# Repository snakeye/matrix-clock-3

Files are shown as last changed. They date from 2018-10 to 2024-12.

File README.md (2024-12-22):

# LED Matrix Clock v3

## Overview
Imagine combining the charm of retro LED displays with modern smart technology. **LED Matrix Clock v3** is a creative DIY project that transforms five 8x8 LED matrices into a sleek timepiece. Powered by an ESP8266 microcontroller, this clock not only displays the current time but also keeps it accurate by syncing with an NTP server. The DS3231 RTC module ensures reliability, while automatic daylight saving adjustments make it smarter than your average clock. Built using the Arduino framework and developed in the PlatformIO environment, this project is a perfect blend of classic aesthetics and cutting-edge convenience.

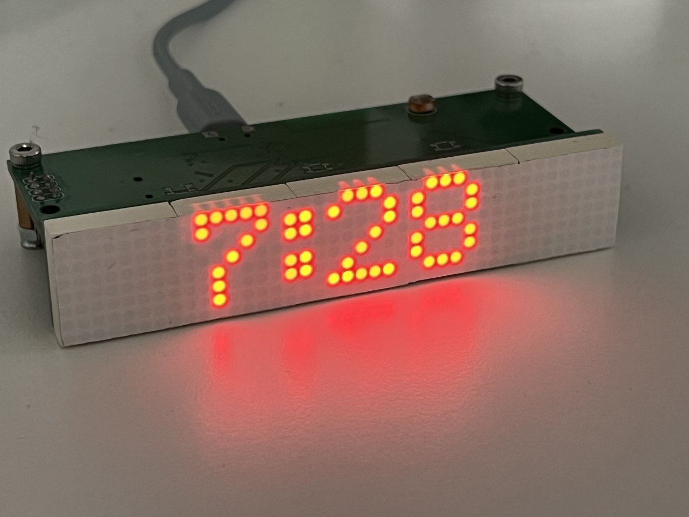
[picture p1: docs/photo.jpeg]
LED Matrix Clock v3


## Features
- **Time Display**: Shows the current time in the local time zone.
- **Automatic Daylight Calculation**: Adjusts for daylight saving time automatically.
- **NTP Synchronization**: Regular updates to the RTC clock via NTP ensure time accuracy.
- **Automatic Brightness**: The display brightness is adjusted according to ambient lighting.

## Hardware Requirements
- **ESP8266 (ESP-12 Module)**
- **5 x 8x8 LED Matrices using MAX7219 drivers**
- **DS3231 RTC Module**

## Software Requirements
- **PlatformIO** (installed via Python Pipenv)
- **Arduino Framework**
- **Python 3.x**

## Installation Instructions

### 1. Clone the Repository
```bash
git clone https://github.com/snakeye/matrix-clock-3.git
cd matrix-clock-3
```

### 3. Set Up the Environment
Ensure you have **Python 3.x** installed. Use Pipenv to install PlatformIO and set up the environment:
```bash
pip install pipenv
pipenv install --dev
pipenv shell
```
This command will install PlatformIO and any additional dependencies needed for the project.

### 2. Configure WiFi Connection
Before building the firmware, set up your WiFi connection:
1. Locate the file `src/config.cpp.example` in the repository.
2. Rename the file to `src/config.cpp`:
   ```bash
   mv src/config.cpp.example src/config.cpp
   ```
3. Open `src/config.cpp` in a text editor and update the placeholders with your WiFi network name (SSID) and password:
   ```cpp
   const char* ssid = "YourNetworkName";
   const char* password = "YourNetworkPassword";
   ```

### 4. Build the Firmware
Use the following command within the Pipenv shell to build the firmware:
```bash
platformio run
```

### 5. Upload the Firmware
Ensure your ESP8266 is connected via USB, and upload the firmware using:
```bash
platformio run --target upload
```
Following updates can be performed using OTA. Discover devices' IP address and run the following command:
```bash
platformio run --target upload --upload-port 192.168.1.179
```

## Usage
Once the firmware is uploaded, the clock will start running and display the current time. It will automatically adjust for daylight saving time and periodically synchronize with an NTP server.

## Troubleshooting
- Ensure your ESP8266 module is properly connected and powered.
- If the upload fails, check the USB connection and the selected upload port in `platformio.ini`.
- Verify your Wi-Fi credentials are correctly configured in the `src/config.cpp` file.

## License
This project is licensed under the MIT License. See the LICENSE file for more details.

## Contributions
Contributions are welcome! Please fork the repository and create a pull request with your improvements or fixes.

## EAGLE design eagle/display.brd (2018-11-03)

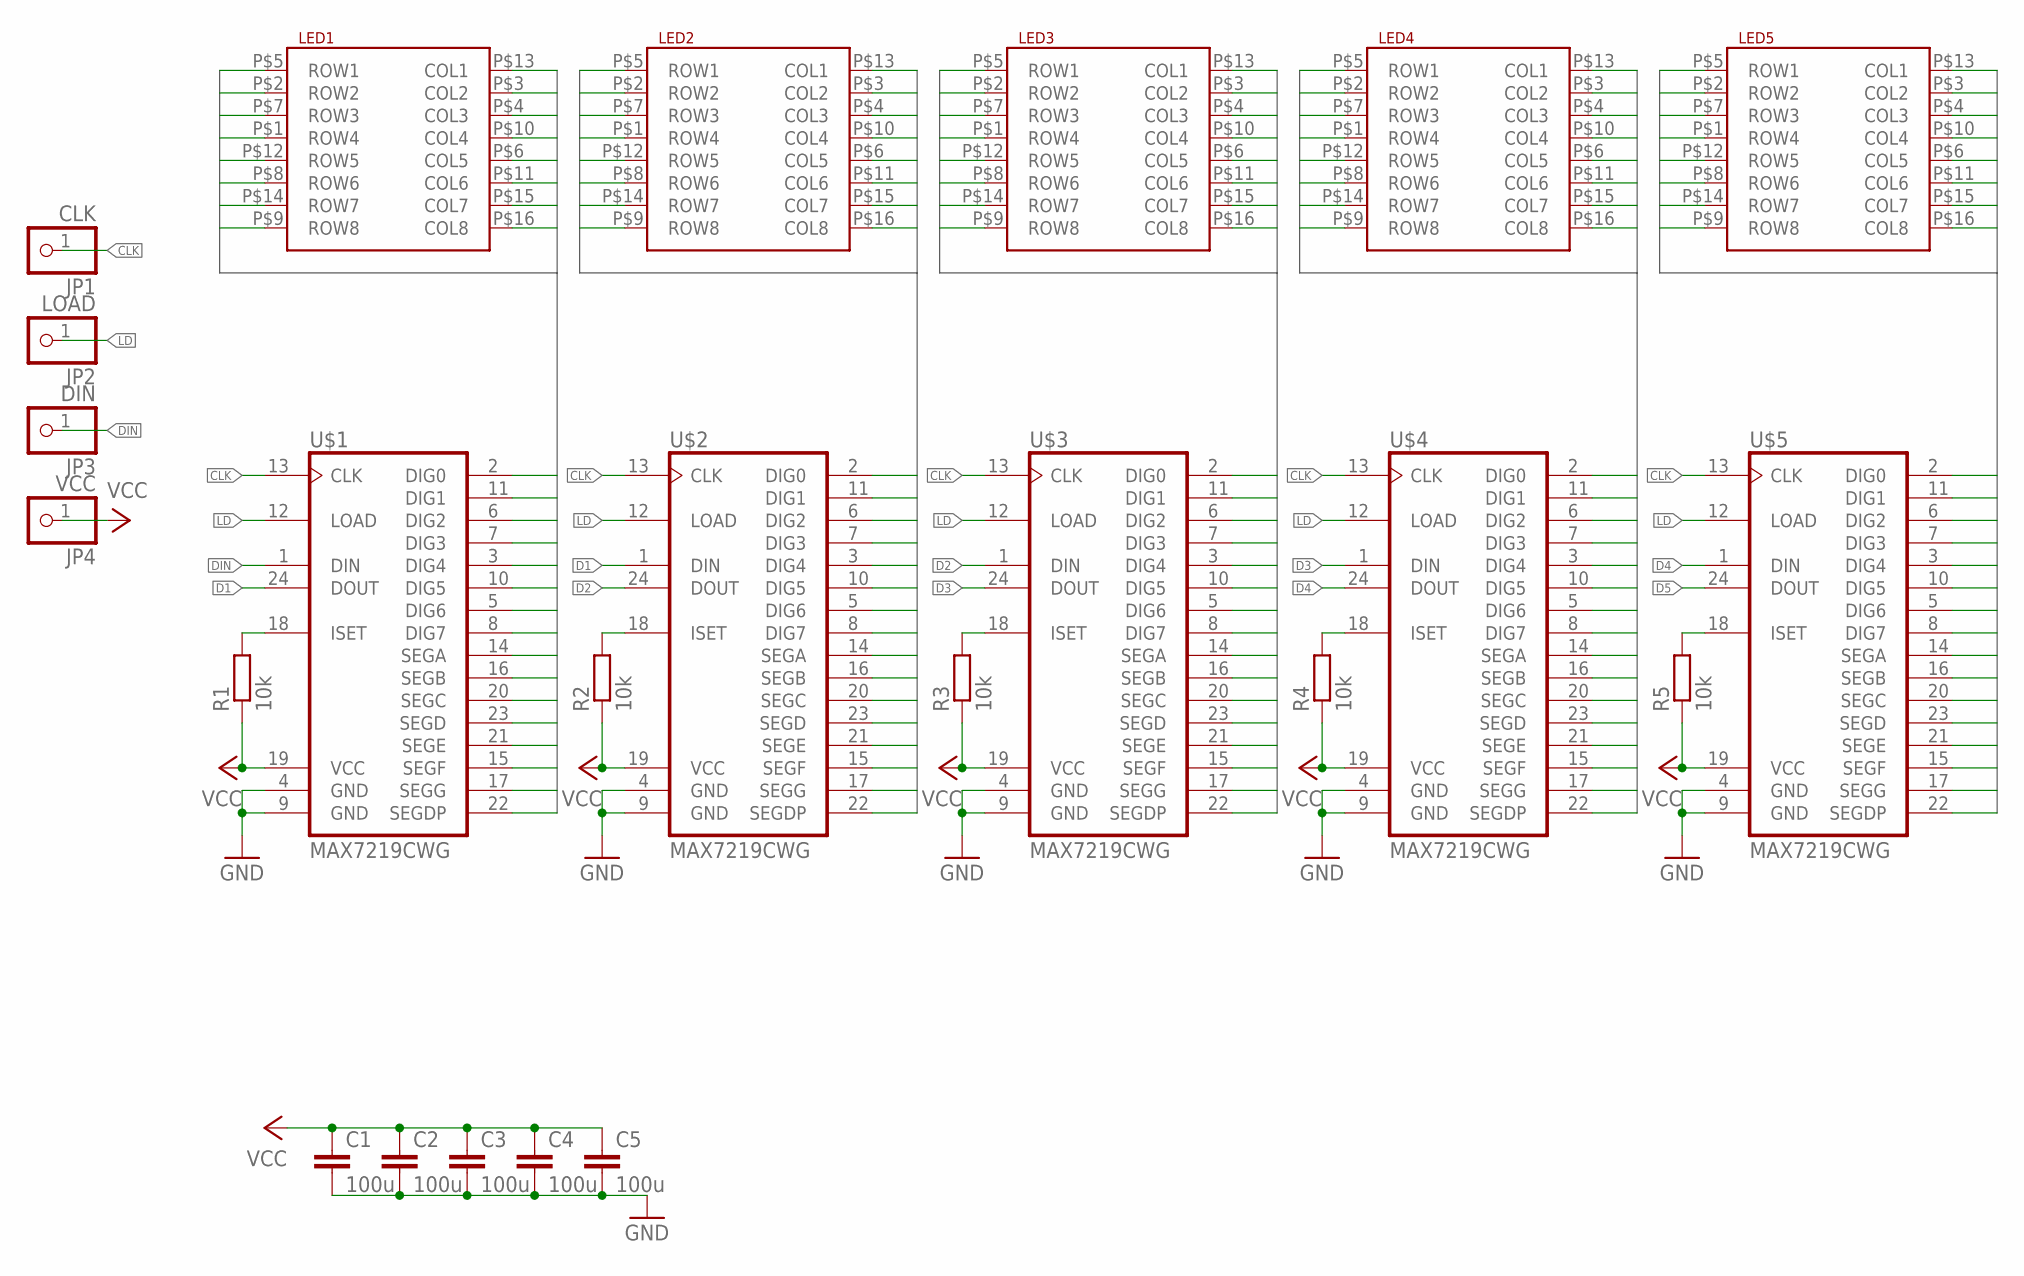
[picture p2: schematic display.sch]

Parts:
C1, C2, C3, C4, C5: 100u; C0805
JP1: CLK; 1X01
JP2: LOAD; 1X01
JP3: DIN; 1X01
JP4: VCC; 1X01
LED1, LED2, LED3, LED4, LED5: LED_8X8_MATRIX07088BH; MATRIX_8X8_20MM
R1, R2, R3, R4, R5: 10k; R0805
U$1, U$2, U$3, U$4, U$5: MAX7219CWG; SO24L

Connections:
CLK: JP1.1, U$1.13 (CLK), U$2.13 (CLK), U$3.13 (CLK), U$4.13 (CLK), U$5.13 (CLK)
D1: U$1.24 (DOUT), U$2.1 (DIN)
D2: U$2.24 (DOUT), U$3.1 (DIN)
D3: U$3.24 (DOUT), U$4.1 (DIN)
D4: U$4.24 (DOUT), U$5.1 (DIN)
D5: U$5.24 (DOUT)
DIN: JP3.1, U$1.1 (DIN)
GND: C1.2, C2.2, C3.2, C4.2, C5.2, U$1.4 (GND), U$1.9 (GND), U$2.4 (GND), U$2.9 (GND), U$3.4 (GND), U$3.9 (GND), U$4.4 (GND), U$4.9 (GND), U$5.4 (GND), U$5.9 (GND)
LD: JP2.1, U$1.12 (LOAD), U$2.12 (LOAD), U$3.12 (LOAD), U$4.12 (LOAD), U$5.12 (LOAD)
MATRIX1_ANODE1: LED1.P$5 (ROW1), U$1.14 (SEGA)
MATRIX1_ANODE2: LED1.P$2 (ROW2), U$1.16 (SEGB)
MATRIX1_ANODE3: LED1.P$7 (ROW3), U$1.20 (SEGC)
MATRIX1_ANODE4: LED1.P$1 (ROW4), U$1.23 (SEGD)
MATRIX1_ANODE5: LED1.P$12 (ROW5), U$1.21 (SEGE)
MATRIX1_ANODE6: LED1.P$8 (ROW6), U$1.15 (SEGF)
MATRIX1_ANODE7: LED1.P$14 (ROW7), U$1.17 (SEGG)
MATRIX1_ANODE8: LED1.P$9 (ROW8), U$1.22 (SEGDP)
MATRIX1_CATHODE1: LED1.P$13 (COL1), U$1.2 (DIG0)
MATRIX1_CATHODE2: LED1.P$3 (COL2), U$1.11 (DIG1)
MATRIX1_CATHODE3: LED1.P$4 (COL3), U$1.6 (DIG2)
MATRIX1_CATHODE4: LED1.P$10 (COL4), U$1.7 (DIG3)
MATRIX1_CATHODE5: LED1.P$6 (COL5), U$1.3 (DIG4)
MATRIX1_CATHODE6: LED1.P$11 (COL6), U$1.10 (DIG5)
MATRIX1_CATHODE7: LED1.P$15 (COL7), U$1.5 (DIG6)
MATRIX1_CATHODE8: LED1.P$16 (COL8), U$1.8 (DIG7)
MATRIX2_ANODE1: LED2.P$5 (ROW1), U$2.14 (SEGA)
MATRIX2_ANODE2: LED2.P$2 (ROW2), U$2.16 (SEGB)
MATRIX2_ANODE3: LED2.P$7 (ROW3), U$2.20 (SEGC)
MATRIX2_ANODE4: LED2.P$1 (ROW4), U$2.23 (SEGD)
MATRIX2_ANODE5: LED2.P$12 (ROW5), U$2.21 (SEGE)
MATRIX2_ANODE6: LED2.P$8 (ROW6), U$2.15 (SEGF)
MATRIX2_ANODE7: LED2.P$14 (ROW7), U$2.17 (SEGG)
MATRIX2_ANODE8: LED2.P$9 (ROW8), U$2.22 (SEGDP)
MATRIX2_CATHODE1: LED2.P$13 (COL1), U$2.2 (DIG0)
MATRIX2_CATHODE2: LED2.P$3 (COL2), U$2.11 (DIG1)
MATRIX2_CATHODE3: LED2.P$4 (COL3), U$2.6 (DIG2)
MATRIX2_CATHODE4: LED2.P$10 (COL4), U$2.7 (DIG3)
MATRIX2_CATHODE5: LED2.P$6 (COL5), U$2.3 (DIG4)
MATRIX2_CATHODE6: LED2.P$11 (COL6), U$2.10 (DIG5)
MATRIX2_CATHODE7: LED2.P$15 (COL7), U$2.5 (DIG6)
MATRIX2_CATHODE8: LED2.P$16 (COL8), U$2.8 (DIG7)
MATRIX3_ANODE1: LED3.P$5 (ROW1), U$3.14 (SEGA)
MATRIX3_ANODE2: LED3.P$2 (ROW2), U$3.16 (SEGB)
MATRIX3_ANODE3: LED3.P$7 (ROW3), U$3.20 (SEGC)
MATRIX3_ANODE4: LED3.P$1 (ROW4), U$3.23 (SEGD)
MATRIX3_ANODE5: LED3.P$12 (ROW5), U$3.21 (SEGE)
MATRIX3_ANODE6: LED3.P$8 (ROW6), U$3.15 (SEGF)
MATRIX3_ANODE7: LED3.P$14 (ROW7), U$3.17 (SEGG)
MATRIX3_ANODE8: LED3.P$9 (ROW8), U$3.22 (SEGDP)
MATRIX3_CATHODE1: LED3.P$13 (COL1), U$3.2 (DIG0)
MATRIX3_CATHODE2: LED3.P$3 (COL2), U$3.11 (DIG1)
MATRIX3_CATHODE3: LED3.P$4 (COL3), U$3.6 (DIG2)
MATRIX3_CATHODE4: LED3.P$10 (COL4), U$3.7 (DIG3)
MATRIX3_CATHODE5: LED3.P$6 (COL5), U$3.3 (DIG4)
MATRIX3_CATHODE6: LED3.P$11 (COL6), U$3.10 (DIG5)
MATRIX3_CATHODE7: LED3.P$15 (COL7), U$3.5 (DIG6)
MATRIX3_CATHODE8: LED3.P$16 (COL8), U$3.8 (DIG7)
MATRIX4_ANODE1: LED4.P$5 (ROW1), U$4.14 (SEGA)
MATRIX4_ANODE2: LED4.P$2 (ROW2), U$4.16 (SEGB)
MATRIX4_ANODE3: LED4.P$7 (ROW3), U$4.20 (SEGC)
MATRIX4_ANODE4: LED4.P$1 (ROW4), U$4.23 (SEGD)
MATRIX4_ANODE5: LED4.P$12 (ROW5), U$4.21 (SEGE)
MATRIX4_ANODE6: LED4.P$8 (ROW6), U$4.15 (SEGF)
MATRIX4_ANODE7: LED4.P$14 (ROW7), U$4.17 (SEGG)
MATRIX4_ANODE8: LED4.P$9 (ROW8), U$4.22 (SEGDP)
MATRIX4_CATHODE1: LED4.P$13 (COL1), U$4.2 (DIG0)
MATRIX4_CATHODE2: LED4.P$3 (COL2), U$4.11 (DIG1)
MATRIX4_CATHODE3: LED4.P$4 (COL3), U$4.6 (DIG2)
MATRIX4_CATHODE4: LED4.P$10 (COL4), U$4.7 (DIG3)
MATRIX4_CATHODE5: LED4.P$6 (COL5), U$4.3 (DIG4)
MATRIX4_CATHODE6: LED4.P$11 (COL6), U$4.10 (DIG5)
MATRIX4_CATHODE7: LED4.P$15 (COL7), U$4.5 (DIG6)
MATRIX4_CATHODE8: LED4.P$16 (COL8), U$4.8 (DIG7)
MATRIX5_ANODE1: LED5.P$5 (ROW1), U$5.14 (SEGA)
MATRIX5_ANODE2: LED5.P$2 (ROW2), U$5.16 (SEGB)
MATRIX5_ANODE3: LED5.P$7 (ROW3), U$5.20 (SEGC)
MATRIX5_ANODE4: LED5.P$1 (ROW4), U$5.23 (SEGD)
MATRIX5_ANODE5: LED5.P$12 (ROW5), U$5.21 (SEGE)
MATRIX5_ANODE6: LED5.P$8 (ROW6), U$5.15 (SEGF)
MATRIX5_ANODE7: LED5.P$14 (ROW7), U$5.17 (SEGG)
MATRIX5_ANODE8: LED5.P$9 (ROW8), U$5.22 (SEGDP)
MATRIX5_CATHODE1: LED5.P$13 (COL1), U$5.2 (DIG0)
MATRIX5_CATHODE2: LED5.P$3 (COL2), U$5.11 (DIG1)
MATRIX5_CATHODE3: LED5.P$4 (COL3), U$5.6 (DIG2)
MATRIX5_CATHODE4: LED5.P$10 (COL4), U$5.7 (DIG3)
MATRIX5_CATHODE5: LED5.P$6 (COL5), U$5.3 (DIG4)
MATRIX5_CATHODE6: LED5.P$11 (COL6), U$5.10 (DIG5)
MATRIX5_CATHODE7: LED5.P$15 (COL7), U$5.5 (DIG6)
MATRIX5_CATHODE8: LED5.P$16 (COL8), U$5.8 (DIG7)
unnamed: R5.2, U$5.18 (ISET)
unnamed: R1.2, U$1.18 (ISET)
unnamed: R2.2, U$2.18 (ISET)
unnamed: R3.2, U$3.18 (ISET)
unnamed: R4.2, U$4.18 (ISET)
VCC: C1.1, C2.1, C3.1, C4.1, C5.1, JP4.1, R1.1, R2.1, R3.1, R4.1, R5.1, U$1.19 (VCC), U$2.19 (VCC), U$3.19 (VCC), U$4.19 (VCC), U$5.19 (VCC)

Board: 2 copper layers, 24 parts (15 on the bottom side), 94 nets, no tracks yet.

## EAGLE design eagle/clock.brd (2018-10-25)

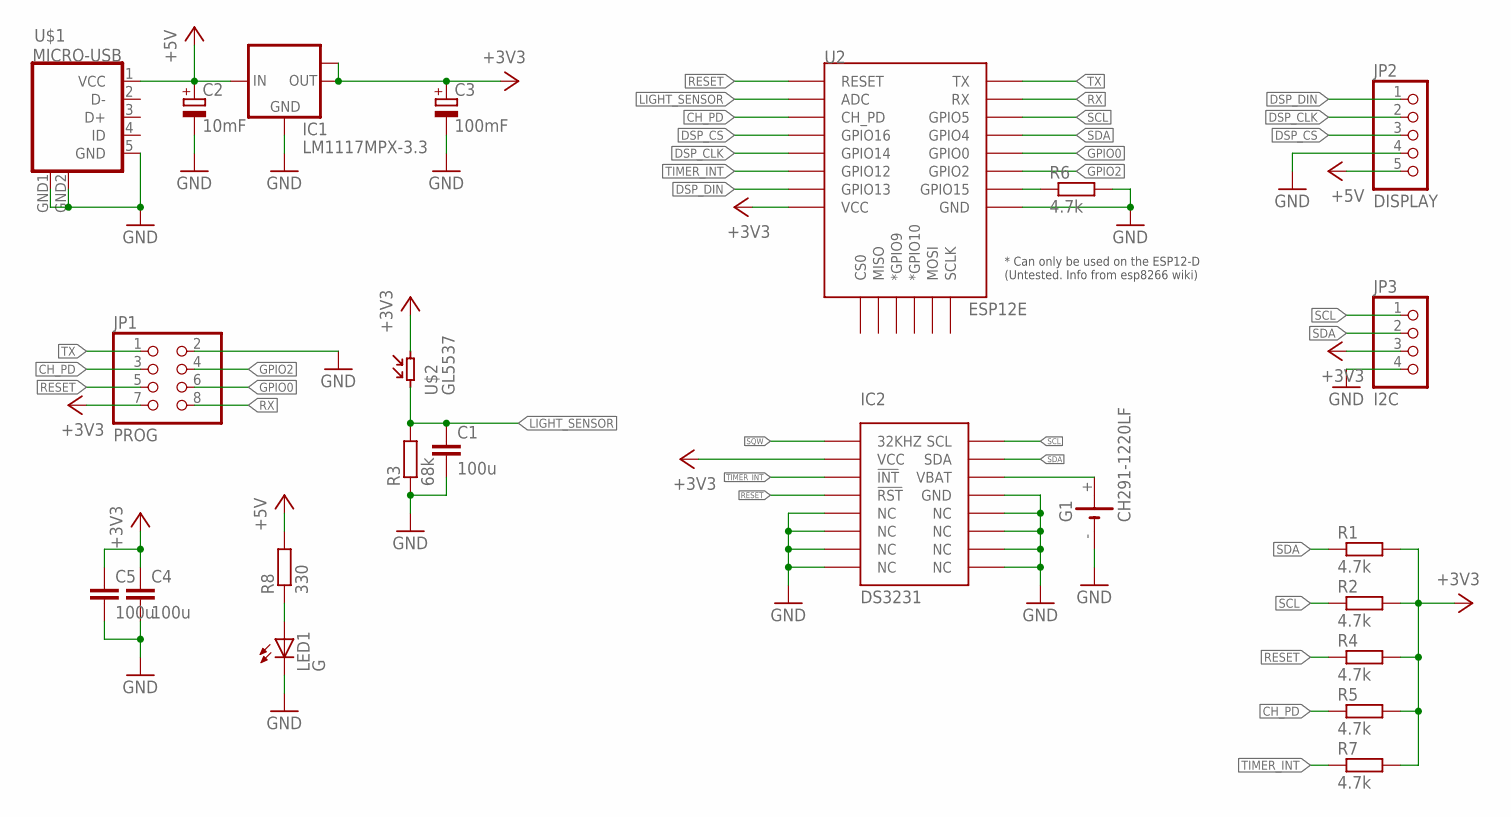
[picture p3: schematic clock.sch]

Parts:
C1, C4, C5: 100u; C0805
C2: 10mF; A/3216-18W
C3: 100mF; A/3216-18W
G1: CH291-1220LF
IC1: LM1117MPX-3.3; SOT223
IC2: DS3231; SOIC-16W
JP1: PROG; 2X04
JP2: DISPLAY; 1X05
JP3: I2C; 1X04
LED1: G; CHIPLED_0805
R1, R2, R4, R5, R6, R7: 4.7k; M0805
R3: 68k; M0805
R8: 330; M0805
U2: ESP12E; ESP12E-SMD
U$1: MICRO-USB
U$2: GL5537; GL55

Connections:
+3V3: C3.+, C4.1, C5.1, IC1.2 (OUT), IC1.TAB (OUT1), IC2.2 (VCC), JP1.7, JP3.3, R1.2, R2.2, R4.2, R5.2, R7.2, U2.VCC, U$2.P$2
+5V: C2.+, IC1.3 (IN), JP2.5, R8.2, U$1.1 (VCC)
CH_PD: JP1.3, R5.1, U2.CH_PD
DSP_CLK: JP2.2, U2.GPIO14
DSP_CS: JP2.3, U2.GPIO16
DSP_DIN: JP2.1, U2.GPIO13
GND: C1.2, C2.-, C3.-, C4.2, C5.2, G1.-, IC1.1 (GND), IC2.5 (NC), IC2.6 (NC), IC2.7 (NC), IC2.8 (NC), IC2.9 (NC), IC2.10 (NC), IC2.11 (NC), IC2.12 (NC), IC2.13 (GND), JP1.2, JP2.4, JP3.4, LED1.C, R3.1, R6.2, U2.GND, U$1.5 (GND), U$1.GND1 (GND), U$1.GND2 (GND)
GPIO0: JP1.6, U2.GPIO0
GPIO2: JP1.4, U2.GPIO2
GPIO15: R6.1, U2.GPIO15
LIGHT_SENSOR: C1.1, R3.2, U2.ADC, U$2.P$1
unnamed: LED1.A, R8.1
unnamed: G1.+, IC2.14 (VBAT)
RESET: IC2.4 (!RST), JP1.5, R4.1, U2.RESET
RX: JP1.8, U2.RXD0 (RX)
SCL: IC2.16 (SCL), JP3.1, R2.1, U2.GPIO5
SDA: IC2.15 (SDA), JP3.2, R1.1, U2.GPIO4
SQW: IC2.1 (32KHZ)
TIMER_INT: IC2.3 (!INT), R7.1, U2.GPIO12
TX: JP1.1, U2.TXD0 (TX)

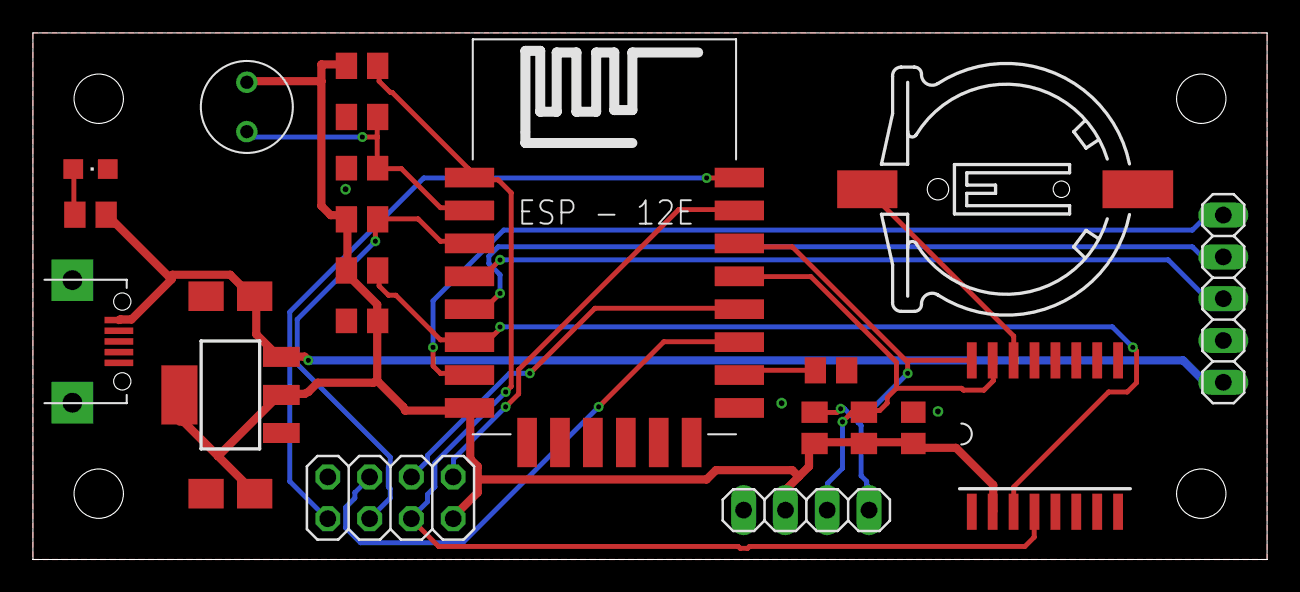
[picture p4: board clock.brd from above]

Board: 2 copper layers, 75.0 x 32.0 mm, 23 parts (0 on the bottom side), 19 nets.

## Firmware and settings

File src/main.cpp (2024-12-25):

#include <Arduino.h>

//
#include <Time.h>
#include <TimeLib.h>

#include <Timezone.h>

//
#include <WiFiUdp.h>
#include <NTPClient.h>

//
#include <Wire.h>
#include <RtcDS3231.h>

//
#include <DNSServer.h>

//
#include <ESP8266mDNS.h>
#include <ArduinoOTA.h>

//
#include <RecurringTask.h>

//
#include <OneButton.h>

#include "LedMatrixDisplay.h"

#include "config.h"

#define INTENSITY_MEASUREMENTS 40

#define PIN_BUTTON 2

#define MODE_RESET_DELAY 15000

//
using namespace LedMatrixDisplay;

// matrix type definition
typedef Matrix<8, 8> TMatrix;

// matrix array definition
typedef MatrixArray<TMatrix, 5, 1> TMatrixArray;

// canvas definition
typedef Canvas<TMatrixArray> TCanvas;

// display definition
typedef DisplayColumnCathode<TCanvas, 15> TDisplay;

TDisplay display;

// NTP
WiFiUDP ntpUDP;
const char *ntpServer = "pool.ntp.org";
NTPClient timeClient(ntpUDP, ntpServer);
const unsigned long ntpUpdateIntervalMillis = (3600 * 3) * 1000; // update every 3 hours

// RTC clock DS3231
// RTC keeps time in UTC!
RtcDS3231<TwoWire> rtcClock(Wire);

// Time zone Europe/Berlin
TimeChangeRule CEST = {"CEST", Last, Sun, Mar, 2, 60 * 2};
TimeChangeRule CET = {"CET", Last, Sun, Oct, 2, 60 * 1};
Timezone timezone(CEST, CET);

//
static int intensity = 2;
static int targetIntensity = 2;

//
typedef enum
{
  MODE_TIME_SHORT,
  MODE_TIME_LONG,
  MODE_DATE,
  MODE_YEAR,
  MODE_TEMP,
  MODE_IP,
} DisplayMode;

DisplayMode displayMode = MODE_TIME_SHORT;

unsigned long modeChanged = 0;

//
OneButton btn = OneButton(
    PIN_BUTTON, // Input pin for the button
    true,       // Button is active LOW
    false       // Enable internal pull-up resistor
);

/**
 * @param val
 * @return char
 */
inline char digit(int val)
{
  return '0' + val;
}

/**
 * @param str
 */
void printTextCentered(const char *str)
{
  const int textWidth = display.getTextWidth(str);
  const int textOffset = ((int)display.width - textWidth) / 2;
  display.drawText(textOffset, 0, str);
}

/**
 *
 */
void printTimeAnimated(const char *strOld, const char *strNew, int frame)
{
  const int textWidth = display.getTextWidth(strNew);
  const int textOffset = ((int)display.width - textWidth) / 2;

  int x0 = textOffset;

  for (unsigned int i = 0; strNew[i] != '\0' && x0 < (int)display.width; i++)
  {
    unsigned int charWidth;
    if (strOld[i] != strNew[i])
    {
      charWidth = display.drawChar(x0, frame - 8, strOld[i]);
      display.drawChar(x0, frame, strNew[i]);
    }
    else
    {
      charWidth = display.drawChar(x0, 0, strNew[i]);
    }
    x0 += charWidth > 0 ? charWidth + 1 : 0;
  }
}

/**
 *
 */
void onOTAStart()
{
  display.setIntensity(2);
  display.clear();
  printTextCentered("*>...");
  display.commit();
}

/**
 *
 */
void onOTAEnd()
{
  display.clear();
  printTextCentered("Done");
  display.commit();
}

/**
 *
 */
void onClickButton()
{
  switch (displayMode)
  {
  case MODE_TIME_SHORT:
    displayMode = MODE_TIME_LONG;
    break;
  case MODE_TIME_LONG:
    displayMode = MODE_DATE;
    break;
  case MODE_DATE:
    displayMode = MODE_YEAR;
    break;
  case MODE_YEAR:
    displayMode = MODE_TEMP;
    break;
  case MODE_TEMP:
    displayMode = MODE_IP;
    break;
  case MODE_IP:
    displayMode = MODE_TIME_SHORT;
    break;
  }

  modeChanged = millis();
}

/**
 *
 */
void setup()
{
  Serial.begin(115200);
  delay(100);
  Serial.println("\n\nLED Matrix Clock v3");

  //
  btn.attachClick(onClickButton);

  // Init RTC
  rtcClock.Begin();

  //
  display.init();
  display.setIntensity(2);
  display.clear();
  printTextCentered("Hello");
  display.commit();

  //
  WiFi.mode(WIFI_STA);
  WiFi.setHostname(deviceName);
  WiFi.begin(ssid, password);
  while (WiFi.status() != WL_CONNECTED)
  {
    delay(1000);
  }
  Serial1.println("WiFi connected");

  //
  MDNS.begin(hostName);

  //
  timeClient.begin();
  timeClient.setUpdateInterval(ntpUpdateIntervalMillis);

  // Over-the-Air update
  ArduinoOTA.onStart([]()
                     { onOTAStart(); });
  ArduinoOTA.onEnd([]()
                   { onOTAEnd(); });
  ArduinoOTA.begin();
}

/**
 * @brief
 *
 * @param str
 * @param local
 * @param dots
 */
void sprintTimeShort(char *str, const time_t local, bool dots)
{
  int h = hour(local);
  int m = minute(local);
  // int s = second(local);
  unsigned int i = 0;

  // draw time
  if (h >= 10)
  {
    str[i++] = digit(h / 10);
  }
  str[i++] = digit(h % 10);

  str[i++] = dots ? ':' : ':';

  //
  str[i++] = digit(m / 10);
  str[i++] = digit(m % 10);

  str[i++] = 0;
}

/**
 *
 */
void sprintTimeLong(char *str, const time_t local, bool dots)
{
  int h = hour(local);
  int m = minute(local);
  int s = second(local);

  unsigned int i = 0;

  // draw time
  if (h >= 10)
  {
    str[i++] = digit(h / 10);
  }
  str[i++] = digit(h % 10);

  str[i++] = ':';

  //
  str[i++] = digit(m / 10);
  str[i++] = digit(m % 10);

  str[i++] = ':';

  //
  str[i++] = digit(s / 10);
  str[i++] = digit(s % 10);

  str[i++] = 0;
}

/**
 * Update RTC time with NTP
 */
void ntpUpdateLoop()
{
  bool hasNtpUpdate = timeClient.update();

  // update if RTC time is not valid or required interval has passed
  if (rtcClock.IsDateTimeValid() || !hasNtpUpdate)
  {
    // no need to update
    return;
  }

  // get updated time
  time_t now = timeClient.getEpochTime();

  Serial.print("Got NTP time: ");
  Serial.println(timeClient.getFormattedTime());

  // update RTC time
  RtcDateTime timeNow = RtcDateTime(year(now), month(now), day(now), hour(now), minute(now), second(now));
  rtcClock.SetDateTime(timeNow);
}

/**
 *
 */
void displayTime(bool dots, DisplayMode mode)
{
  //
  if (!rtcClock.IsDateTimeValid() || !timeClient.isTimeSet())
  {
    // blinking dashes
    printTextCentered(dots ? "--:--" : ":");
    return;
  }

  // get RTC time
  RtcDateTime utc = rtcClock.GetDateTime();

  // convert UTC time to local
  time_t local = timezone.toLocal(utc.Unix32Time());

  static char strTimePrev[12] = {0};
  static char strTime[12] = {0};
  static int frame = 8;

  if (mode == MODE_TIME_SHORT)
  {
    sprintTimeShort(strTime, local, dots);
  }
  else if (mode == MODE_TIME_LONG)
  {
    sprintTimeLong(strTime, local, dots);
  }

  if (strcmp(strTimePrev, strTime) != 0)
  {
    printTimeAnimated(strTimePrev, strTime, frame--);
    if (frame == 0)
    {
      memcpy(strTimePrev, strTime, strlen(strTime));
      frame = 8;
    }
  }
  else
  {
    printTextCentered(strTime);
  }
}

/**
 *
 */
void displayDate()
{
  //
  if (!rtcClock.IsDateTimeValid() || !timeClient.isTimeSet())
  {
    // blinking dashes
    printTextCentered("--/--");
    return;
  }

  // get RTC time
  RtcDateTime utc = rtcClock.GetDateTime();

  // convert UTC time to local
  time_t local = timezone.toLocal(utc.Unix32Time());

  static char strDate[12] = {0};

  int d = day(local);
  int m = month(local);

  sprintf(strDate, "%d/%d", d, m);

  printTextCentered(strDate);
}

/**
 *
 */
void displayYear()
{
  //
  if (!rtcClock.IsDateTimeValid() || !timeClient.isTimeSet())
  {
    // blinking dashes
    printTextCentered("----");
    return;
  }

  // get RTC time
  RtcDateTime utc = rtcClock.GetDateTime();

  // convert UTC time to local
  time_t local = timezone.toLocal(utc.Unix32Time());

  static char strDate[12] = {0};

  int y = year(local);

  sprintf(strDate, "%d", y);

  printTextCentered(strDate);
}

/**
 *
 */
void displayTemp()
{
  RtcTemperature rtcTemp = rtcClock.GetTemperature();

  static char strTemp[12] = {0};
  const float temp = (float)rtcTemp.AsCentiDegC() / 100.0f;
  sprintf(strTemp, "t: %.1f", temp);

  printTextCentered(strTemp);
}

/**
 *
 */
void displayIP()
{
  static char strIp[12] = {0};

  uint32_t ip = WiFi.localIP().v4();

  sprintf(strIp, "IP: .%d", (ip >> 24));
  printTextCentered(strIp);
}

/**
 * Update display
 */
void displayLoop(bool dots)
{
  // Clear display
  display.clear();

  switch (displayMode)
  {
  case MODE_TIME_SHORT:
  case MODE_TIME_LONG:
    displayTime(dots, displayMode);
    break;
  case MODE_DATE:
    displayDate();
    break;
  case MODE_YEAR:
    displayYear();
    break;
  case MODE_TEMP:
    displayTemp();
    break;
  case MODE_IP:
    displayIP();
    break;
  }

  //
  display.commit();

  unsigned long now = millis();

  if (displayMode != MODE_TIME_SHORT && now > modeChanged + MODE_RESET_DELAY)
  {
    displayMode = MODE_TIME_SHORT;
  }
}

/**
 * Calculate average ambient brightness over multiple measures
 */
void intencityMeasureLoop()
{
  static int measures[INTENSITY_MEASUREMENTS] = {0};
  static int currentMeasure = 0;

  measures[currentMeasure++] = (analogRead(A0) * 15) / 1024;

  currentMeasure = currentMeasure % INTENSITY_MEASUREMENTS;

  // calculate average
  int sum = 0;
  for (auto i = 0; i < INTENSITY_MEASUREMENTS; i++)
  {
    sum += measures[i];
  }
  targetIntensity = sum / INTENSITY_MEASUREMENTS;
}

/**
 * Update display intencity
 */
void intencityUpdateLoop()
{
  // change display intensity
  if (intensity < targetIntensity)
  {
    intensity += 1;
    display.setIntensity(intensity);
  }
  else if (intensity > targetIntensity)
  {
    intensity -= 1;
    display.setIntensity(intensity);
  }
}

/**
 *
 */
void loop()
{
  //
  static bool dots = false;

  //
  ArduinoOTA.handle();

  //
  btn.tick();

  //
  RecurringTask::interval(500, []()
                          { dots = !dots; });

  // display update
  RecurringTask::interval(50, []()
                          { displayLoop(dots); });

  // change brightness
  RecurringTask::interval(50, []()
                          { intencityMeasureLoop(); });

  RecurringTask::interval(100, []()
                          { intencityUpdateLoop(); });

  RecurringTask::interval(1000, []()
                          { ntpUpdateLoop(); });

  delay(1);
}

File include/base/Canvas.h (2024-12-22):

#pragma once

#include "base/MatrixArray.h"

#include "font.h"

namespace LedMatrixDisplay
{

  /**
   * @brief Test alignment
   *
   */
  enum TextAlign
  {
    left,
    leftEnd,
    right,
    rightEnd,
    center
  };

  /**
   * @brief Canvas objct providing basic graphics operations
   *
   * @tparam TMatrixArray defines geometry of the matrix array
   */
  template <class TMatrixArray>
  class Canvas : public TMatrixArray
  {
  protected:
    static const unsigned int frameBufferSize = TMatrixArray::width * TMatrixArray::arrayRows;

  protected:
    unsigned char frameBuffer[frameBufferSize] = {0};

  public:
    /**
     * @brief Clear the canvas
     *
     * Set all pixels to zero
     */
    void clear()
    {
      for (unsigned int i = 0; i < frameBufferSize; i++)
      {
        frameBuffer[i] = 0;
      }
    }

    /**
     * @brief Set single pixel
     *
     * @param x
     * @param y
     */
    void setPixel(const int x, const int y)
    {
      unsigned int row = y / TMatrixArray::matrixHeight;
      unsigned int bit = y % TMatrixArray::matrixHeight;

      frameBuffer[TMatrixArray::width * row + x] |= (1 << bit);
    }

    /**
     * @brief Clear single pixel
     *
     * @param x
     * @param y
     */
    void clearPixel(const int x, const int y)
    {
      unsigned int row = y / TMatrixArray::matrixHeight;
      unsigned int bit = y % TMatrixArray::matrixHeight;

      frameBuffer[TMatrixArray::width * row + x] &= ~(1 << bit);
    }

    /**
     * @brief Get current pixel value in the framebuffer
     *
     * @param x
     * @param y
     * @return true
     * @return false
     */
    bool getPixel(const int x, const int y)
    {
      unsigned int row = y / TMatrixArray::matrixHeight;
      unsigned int bit = y % TMatrixArray::matrixHeight;

      return (frameBuffer[TMatrixArray::width * row + x] & (1 << bit)) != 0;
    }

    /**
     * @brief Get the Text Width object
     *
     * @param str
     * @return unsigned int
     */
    unsigned int getTextWidth(const char *str) const
    {
      unsigned int width = 0;

      for (unsigned int i = 0; str[i] != '\0'; i++)
      {
        const unsigned int charWidth = charset_width[(uint8_t)str[i]];
        if (charWidth > 0)
        {
          width += charWidth + 1;
        }
      }

      return width > 0 ? width - 1 : 0;
    }

    /**
     * @brief Draw single character
     *
     * @param x
     * @param y
     * @param ch
     * @return unsigned int
     */
    unsigned int drawChar(const int x, const int y, const unsigned char ch)
    {
      // we draw only first half of ASCII charset
      if (ch > 127)
        return 0;

      unsigned char mask = (y >= 0) ? (0xFF << y) : (0xFF > y);

      // character width
      unsigned int char_width = charset_width[ch];
      if (char_width == 0)
        return 0;

      // character offset
      unsigned int char_offset = charset_offset[ch];

      // draw character
      for (unsigned int j = 0; j < char_width; j++)
      {
        unsigned int col = x + j;
        if (col < TMatrixArray::width)
        {
          // read column pixels from program memory
          unsigned char pixels = charset_char[char_offset + j];

          // shift pixels
          pixels = (y >= 0) ? (pixels << y) : (pixels >> (-y));

          // update canvas
          frameBuffer[col] &= ~(mask);
          frameBuffer[col] |= pixels;
        }
      }

      return char_width;
    }

    /**
     * @brief
     *
     * @param x
     * @param y
     * @param str
     */
    void drawText(const int x, const int y, const char *str)
    {
      // if is not visible, return
      if (y < -8 || y > 8)
        return;

      int x0 = x;

      for (unsigned int i = 0; str[i] != '\0' && x0 < (int)TMatrixArray::width; i++)
      {
        unsigned int char_width = drawChar(x0, y, str[i]);
        if (char_width > 0)
        {
          // position of the next char
          x0 += char_width + 1;
        }
      }
    }
  };

} // namespace LedMatrixDisplay

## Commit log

2018-10-25 Added Eagle files
    [clock.brd, clock.sch, display.brd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]
2018-10-26 removed pinhead
    [display.brd, display.sch]
2018-11-03 display board
    [display.brd, display.sch, driver.brd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]
2024-12-24 Added button, Added display modes
2024-12-25 Return to short time after 15s
    [main.cpp]
